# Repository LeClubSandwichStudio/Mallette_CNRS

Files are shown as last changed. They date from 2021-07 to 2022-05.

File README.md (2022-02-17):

# Mallette_CNRS
Water Analyser Briefcase for scientist
> ### Description

> ### [3D View](https://a360.co/3F3qp8W) - models designed by Mathorel Remi (2021)

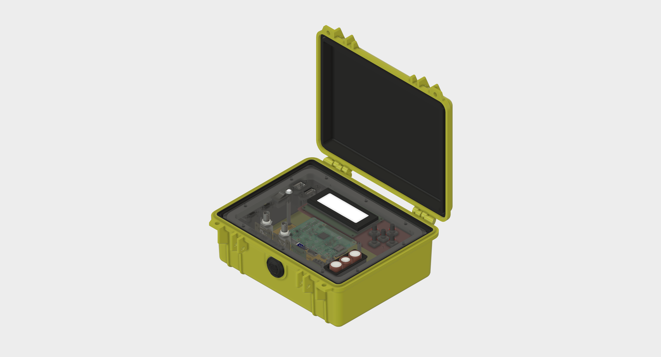
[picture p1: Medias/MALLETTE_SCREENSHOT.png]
mallette screenshot


# Key Features
> ### Hardware

* Protection Case : 
  * Case : [Pelican 1200](https://www.pelican.com/us/en/product/cases/protector/1200) 
  * Panel Frame : [Pelican 1200PF](https://www.pelican.com/us/en/accessory/cases/special-application-panel-frame/1200pf)
* MCU : [Teensy 3.6](https://www.pjrc.com/store/teensy36.html)
* OS : Raspberry Pi 4B - [RaspOS](https://www.raspberrypi.org/software/)
* Sensors : 
  * PH : [SEN0161-V2](https://wiki.dfrobot.com/Gravity__Analog_pH_Sensor_Meter_Kit_V2_SKU_SEN0161-V2)
  * EC : [DFR0300](https://wiki.dfrobot.com/Gravity__Analog_Electrical_Conductivity_Sensor___Meter_V2__K=1__SKU_DFR0300)
  * Temperature
  * Turbidity

> ### Software

# Summary

# Licence

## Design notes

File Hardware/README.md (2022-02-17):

# Bill Of Materials

> MCU
- [Teensy 3.6](https://www.pjrc.com/store/teensy36.html)

> OS
- [Raspberry Pi 4B](https://www.raspberrypi.org/products/raspberry-pi-4-model-b/)

> Sensors
- [DFRobot Analog Turbidity Sensor](https://wiki.dfrobot.com/Turbidity_sensor_SKU__SEN0189)
- [DFRobot Analog EC Meter V2](https://wiki.dfrobot.com/Gravity__Analog_Electrical_Conductivity_Sensor___Meter_V2__K=1__SKU_DFR0300)
- [DFRobot Analog PH Meter V2](https://wiki.dfrobot.com/Gravity__Analog_pH_Sensor_Meter_Kit_V2_SKU_SEN0161-V2)
- [DFRobot Digital Temperature Sensor](https://wiki.dfrobot.com/Waterproof_DS18B20_Digital_Temperature_Sensor__SKU_DFR0198_)

> Shield
- Custom LCSS Teensy Shield

https://a360.co/3LIjGnY

> Others
- Li-Ion Charger
- Li-Iion Battery
- I/O Switch
- Status Led
-

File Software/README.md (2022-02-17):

# Overview 

| Arduino | Raspberry | Local Website | 
|---|:---:|---:|
| Sensors management | OS | Front interface |
| Sensors Journey | Computing | Commands |

Local AP

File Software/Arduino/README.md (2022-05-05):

# BRIEF

Sample Arduino code to use Water Briefcase Analyzer version 1.2

# FEATURES

- measure temperature
- measure electroconductivity
- measure ph
- measure turbidity (with specific formula)
- check serial to read new commands
- send json to serial 

# DEPENDENCIES

- DFROBOT EC : https://github.com/DFRobot/DFRobot_EC
- DFROBOT PH : https://github.com/DFRobot/DFRobot_PH

# HOW TO RUN ARDUINO

- download Arduino software here : https://www.arduino.cc/en/software

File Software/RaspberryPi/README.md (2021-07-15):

# TABLE OF CONTENTS

- OS Installation
- Remote desktop test and installation
- Server and webpage setup
- Main.py setup

# OS Installation

### Installation [RaspOS](https://www.raspberrypi.org/software/)
> id : pi

> mdp : kmvwqazh

### Installation [Clavier AZERTY](https://www.framboise314.fr/clavier-virtuel-matchbox-en-azerty-sur-le-raspberry-pi/)

### Installation de [RaspAP](https://raspap.com/#quick) 

Dans les paramètres en se connectant au point d’accès,  
> modify password to **"kmvwqazh"**

> modify SSID WIFI name to **"Raspberry_OSI_@MAC"** 

> modify IP to **"10.3.141.X"** 

### Installation [XRDP](https://linuxize.com/post/how-to-install-xrdp-on-raspberry-pi/)

# Remote desktop test and installation

**Work In progress**

*Only use if you need to control remotly the Raspi from your personal desktop without working directly on the Raspi*

# Server and webpage setup

### Check for updates
```python
sudo apt-get update
```
### Upgrade if needed 
```python
sudo apt-get upgrade
```
### Reboot Raspi
```python
sudo reboot
```
### Add permission to modify webpage folder

> First write this in terminal :
```python
sudo chmod -R 777 /var/www/
```
> Then continue typing in terminal :
```python
sudo chmod -R 777 /var/www/*
```
> Check your permission and access
```python
ls -l /var/www/html/
```

### Clear webpage contents
> Go to the repository /home/var/www

> Erase all contents in :file_folder: **www**

### Installation Apache
```python
sudo apt install apache2
```
```python
sudo apt install libapache2-mod-php
```
```python
sudo apt remove lighttpd --yes && sudo service apache2 start
```
> Check it
```python
sudo service --status-all
```

### Html folder
> Copy :file_folder: **html** from github repository

> Past :file_folder: **html** into your local Raspi folder /home/var/www

### Test your html page
> Verify that you are connected to the Raspberry Wifi

> Check if there is any issue with the PHP
```python
sudo tail -n 20 /var/log/apache2/error.log
```
> If there is no issue
```python
sudo service apache2 restart
```
> Reboot the Raspi
```python
sudo reboot 
```
:warning: **Even if you can display the webpage, buttons are not yet running** :warning:

# Main.py Setup

> Copy :page_facing_up: **main.py** from github repository

> Past :page_facing_up: **main.py** into your local Raspi folder /home/Desktop

> Check if it is OK

_Please think to connect the teensy and the Raspi by a usb cable !_

_Please think to upload the Arduino code into the teensy !_

```python
cd Desktop
```
```python
sudo python main.py
```

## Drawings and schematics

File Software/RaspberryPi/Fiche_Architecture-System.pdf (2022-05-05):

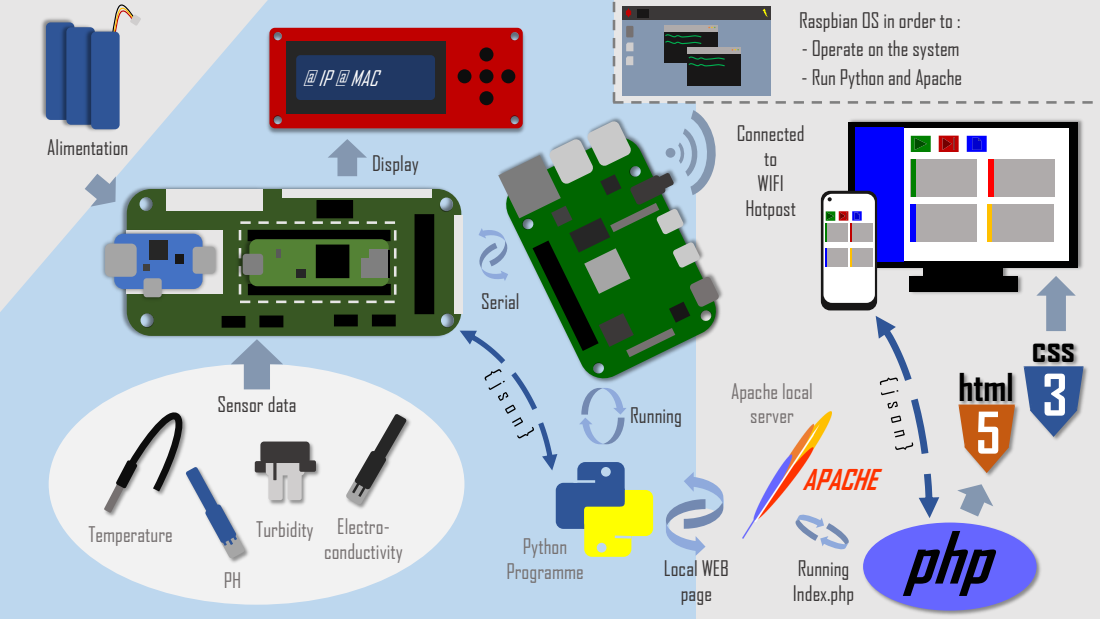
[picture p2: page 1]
php; html 5; css; Sensor data; Alimentation; @ IP @ MAC; Display; Temperature; Turbidity; Electro- conductivity; Serial; Connected to WIFI Hotpost; Running; Python Programme; Apache local server; APACHE; Local WEB page; Running Index.php

Raspbian OS in order to :
- Operate on the system
- Run Python and Apache

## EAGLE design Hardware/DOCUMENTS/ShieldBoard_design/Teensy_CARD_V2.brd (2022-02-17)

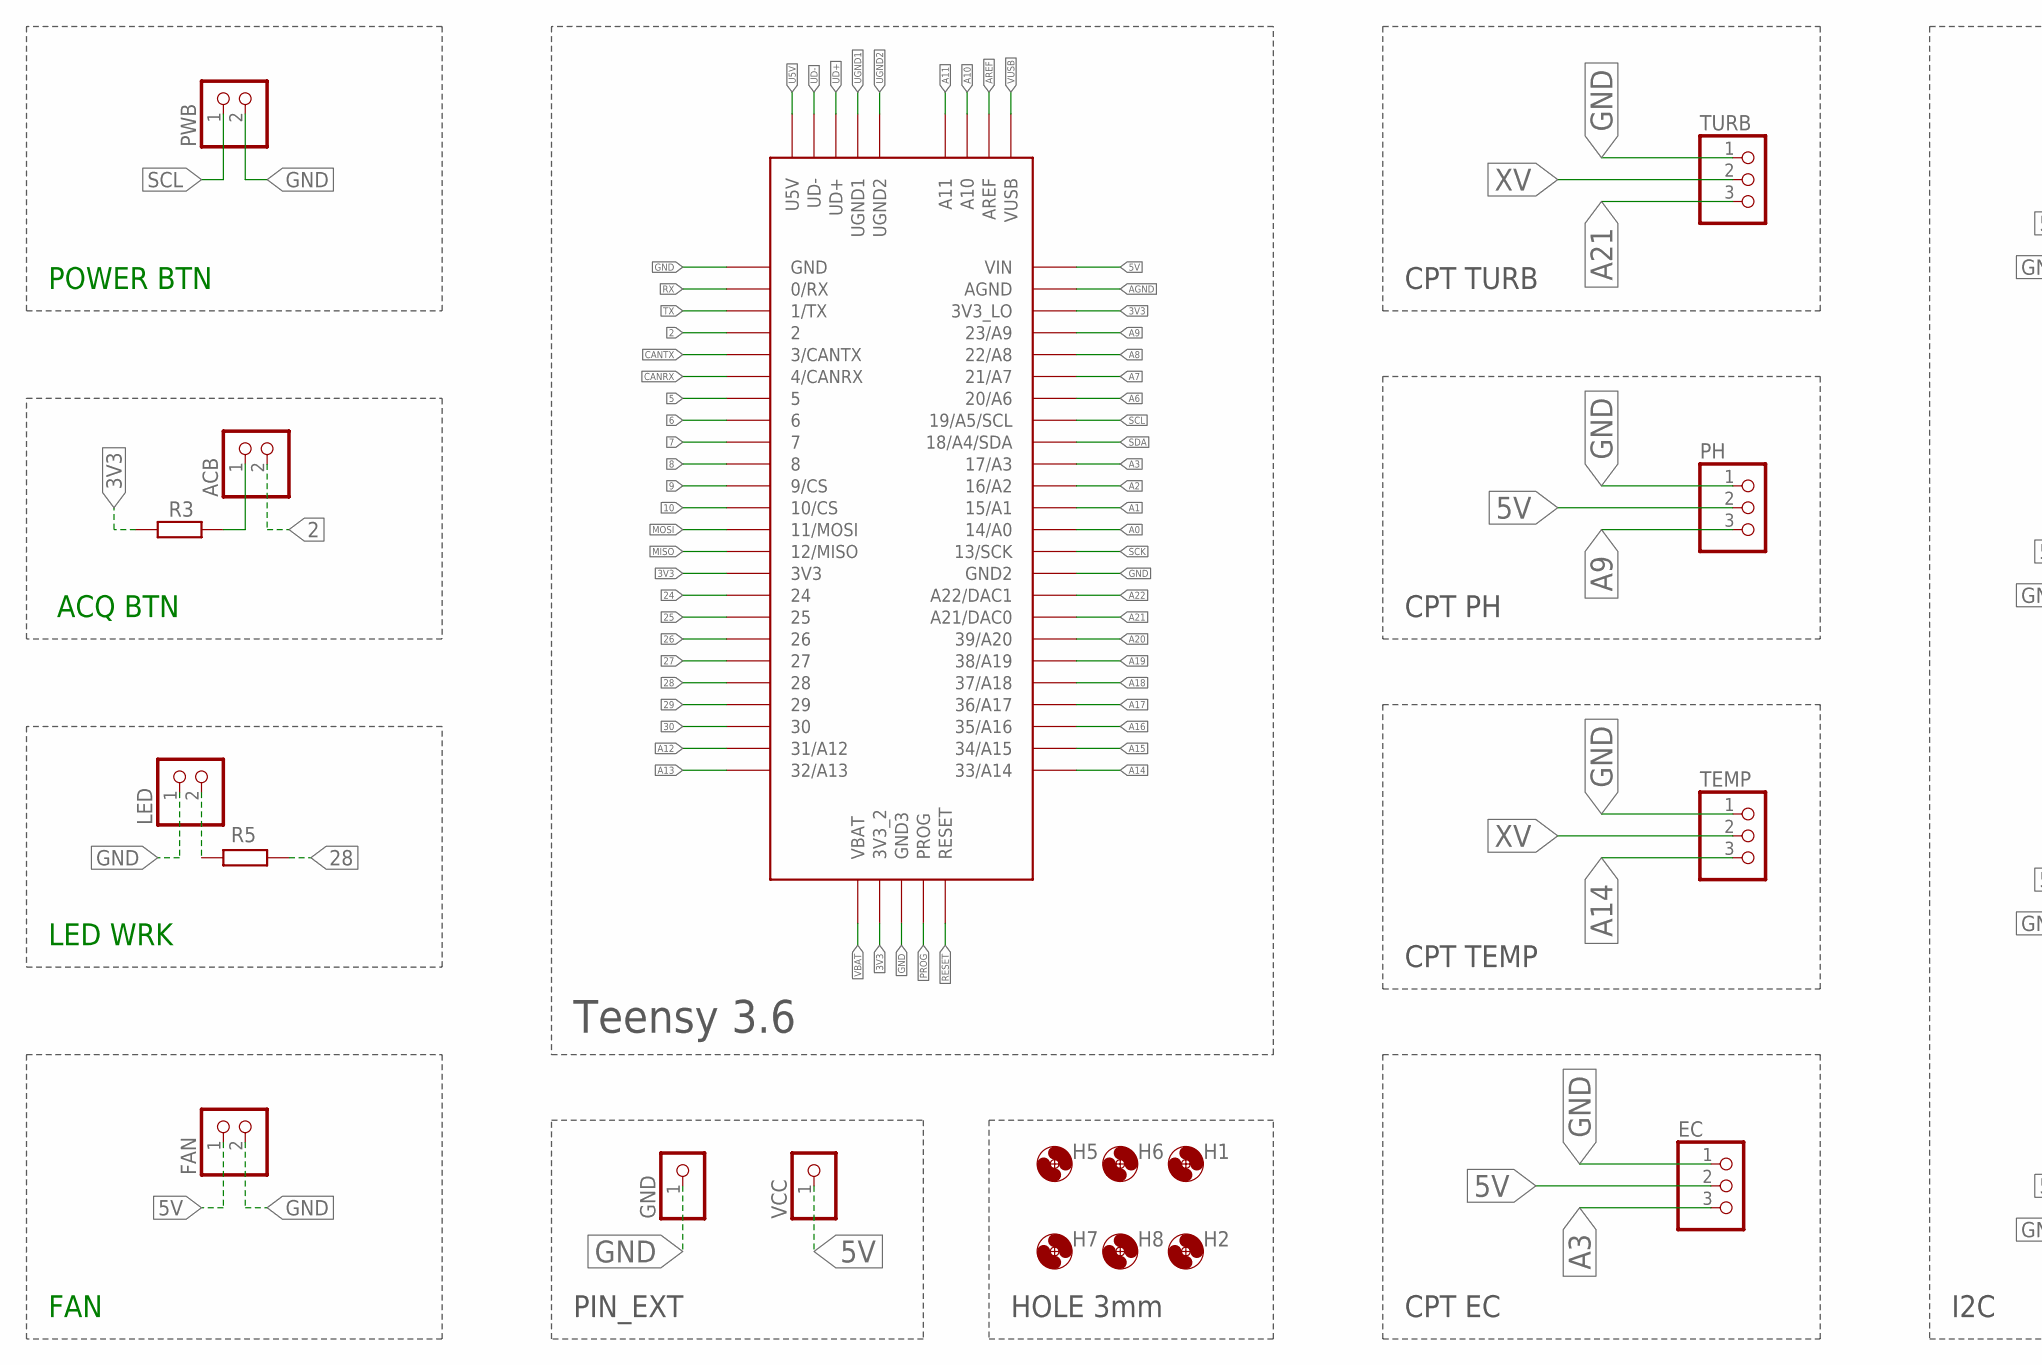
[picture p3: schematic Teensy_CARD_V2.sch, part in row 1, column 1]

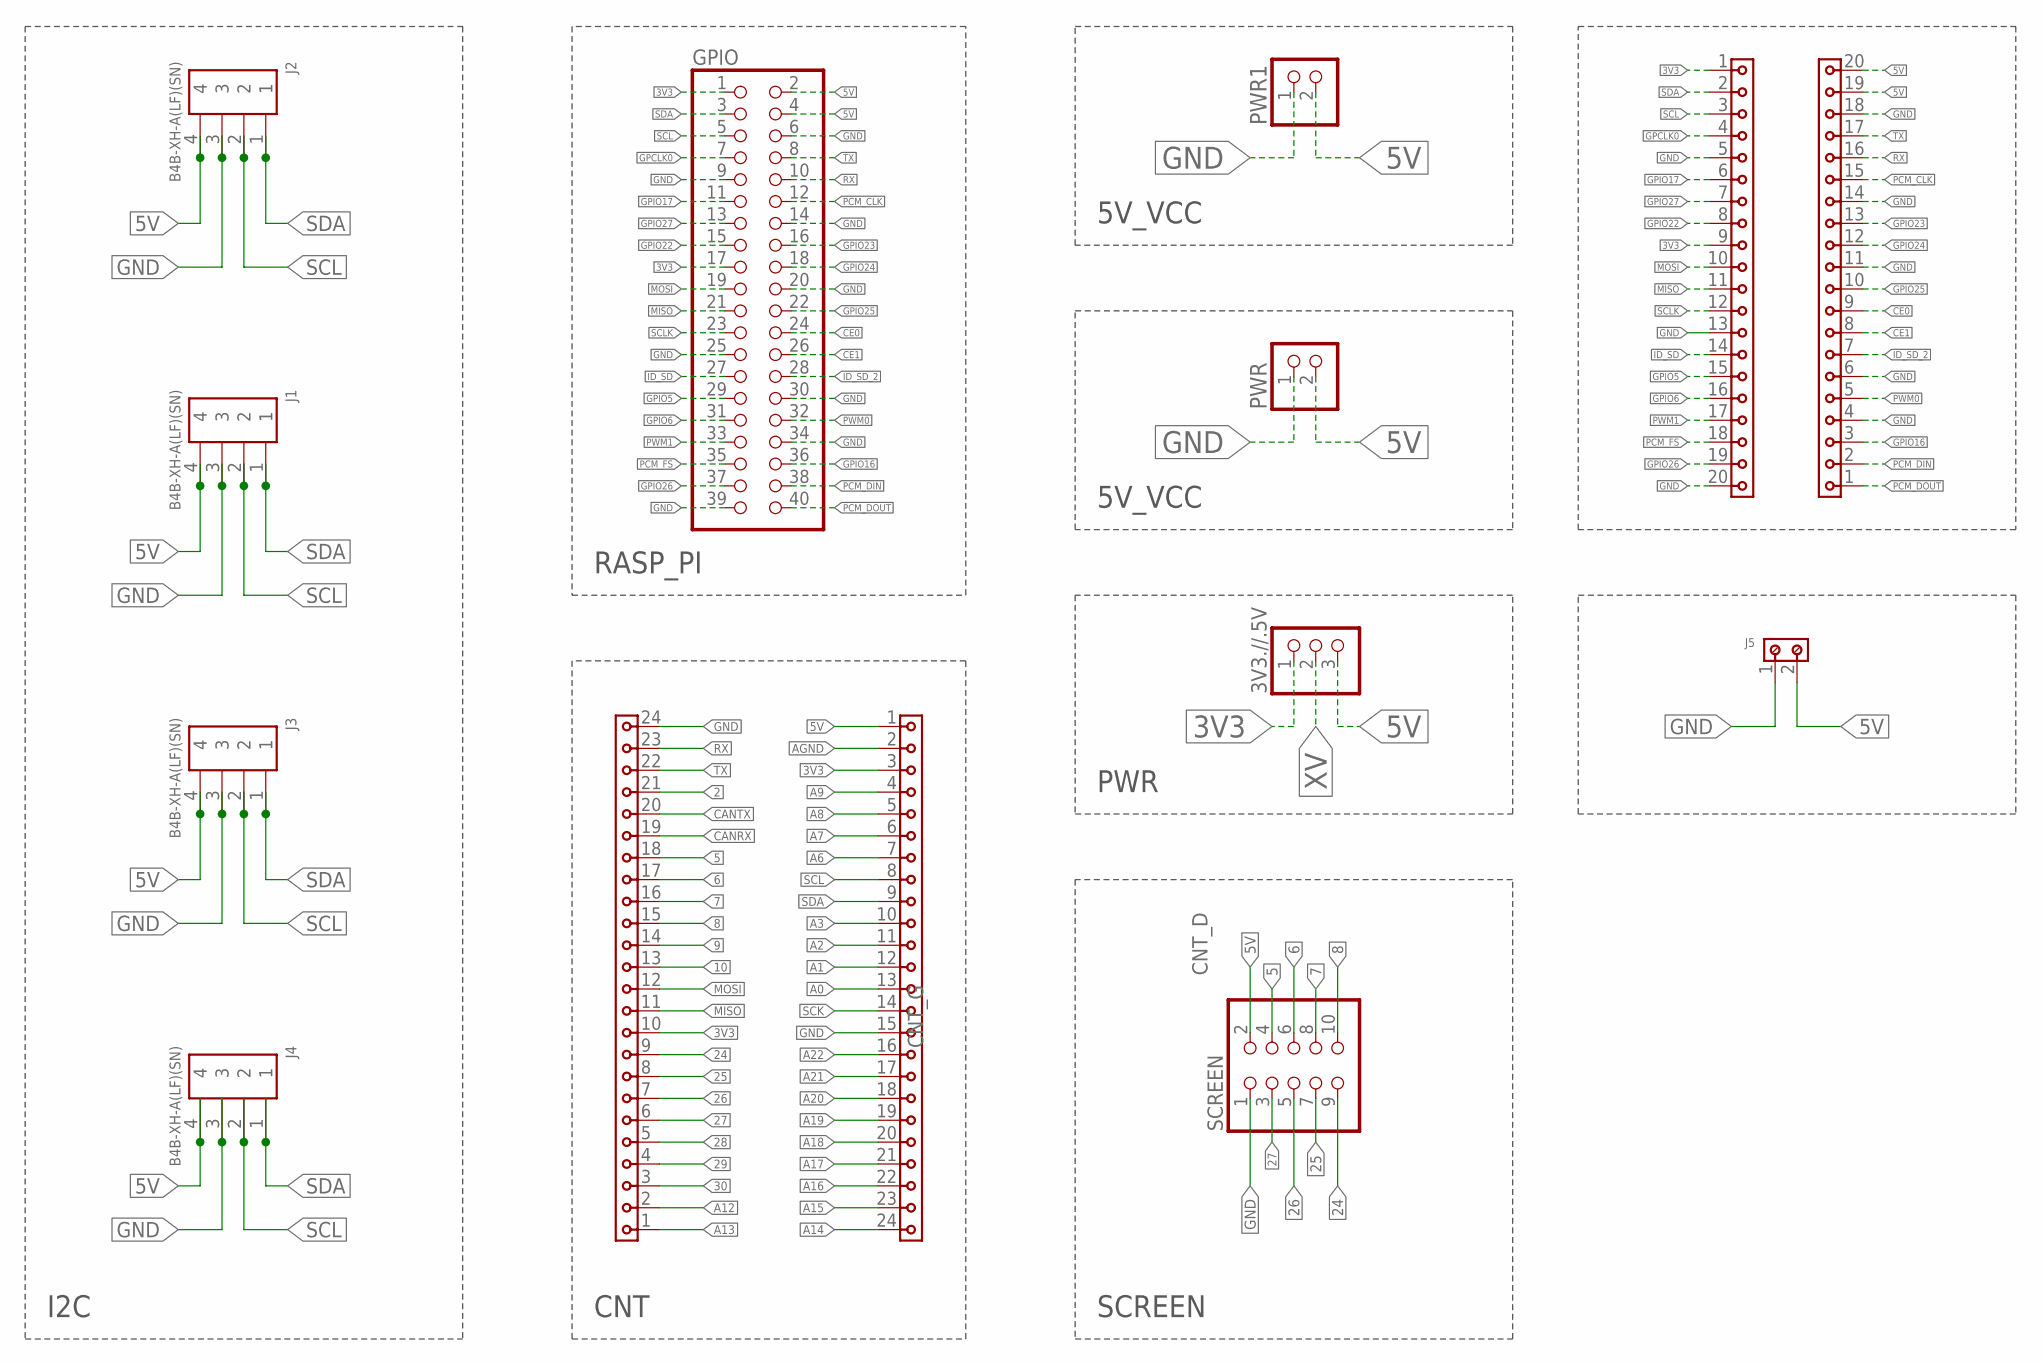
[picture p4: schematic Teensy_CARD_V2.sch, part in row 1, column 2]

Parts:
3V3.//.5V: PINHD-1X3; 1X03
ACB: PINHD-1X2; 1X02
CNT_D: 6130XX11821_61302411821; 61302411821
CNT_G: 6130XX11821_61302411821; 61302411821
EC: PINHD-1X3; 1X03
FAN: PINHD-1X2; 1X02
GND: PINHD-1X1; 1X01
GPIO: PINHD-2X20; 2X20
H1, H2, H5, H6, H7, H8: MOUNT-HOLE3.0; 3,0
J1, J2, J3, J4: B4B-XH-A(LF)(SN)
J5: 691213510002
JP1, JP2: 6130XX11821_61302011821; 61302011821
LED: PINHD-1X2; 1X02
PH: PINHD-1X3; 1X03
PWB: PINHD-1X2; 1X02
PWR, PWR1: PINHD-1X2; 1X02
R3, R5: R-EU_0207/10; 0207/10
SCREEN: PINHD-2X5; 2X05
TEMP: PINHD-1X3; 1X03
TURB: PINHD-1X3; 1X03
U$1: TEENSY_3.5/3.6
VCC: PINHD-1X1; 1X01

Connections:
2: ACB.2, CNT_G.21, U$1.2
3V3: 3V3.//.5V.1, CNT_D.3, CNT_G.10, GPIO.1, GPIO.17, JP1.1, JP1.9, R3.1, U$1.3V3, U$1.3V3_2, U$1.3V3_LO
5: CNT_G.18, SCREEN.4, U$1.5
5V: 3V3.//.5V.3, CNT_D.1, EC.2, FAN.1, GPIO.2, GPIO.4, J1.4, J2.4, J3.4, J4.4, J5.2, JP2.19, JP2.20, PH.2, PWR.2, PWR1.2, SCREEN.2, U$1.VIN, VCC.1
6: CNT_G.17, SCREEN.6, U$1.6
7: CNT_G.16, SCREEN.8, U$1.7
8: CNT_G.15, SCREEN.10, U$1.8
9: CNT_G.14, U$1.9/CS
10: CNT_G.13, U$1.10/CS
24: CNT_G.9, SCREEN.9, U$1.24
25: CNT_G.8, SCREEN.7, U$1.25
26: CNT_G.7, SCREEN.5, U$1.26
27: CNT_G.6, SCREEN.3, U$1.27
28: CNT_G.5, R5.1, U$1.28
29: CNT_G.4, U$1.29
30: CNT_G.3, U$1.30
A0: CNT_D.13, U$1.14/A0
A1: CNT_D.12, U$1.15/A1
A2: CNT_D.11, U$1.16/A2
A3: CNT_D.10, EC.3, U$1.17/A3
A6: CNT_D.7, U$1.20/A6
A7: CNT_D.6, U$1.21/A7
A8: CNT_D.5, U$1.22/A8
A9: CNT_D.4, PH.3, U$1.23/A9
A10: U$1.A10
A11: U$1.A11
A12: CNT_G.2, U$1.31/A12
A13: CNT_G.1, U$1.32/A13
A14: CNT_D.24, TEMP.3, U$1.33/A14
A15: CNT_D.23, U$1.34/A15
A16: CNT_D.22, U$1.35/A16
A17: CNT_D.21, U$1.36/A17
A18: CNT_D.20, U$1.37/A18
A19: CNT_D.19, U$1.38/A19
A20: CNT_D.18, U$1.39/A20
A21: CNT_D.17, TURB.3, U$1.21/DAC0 (A21/DAC0)
A22: CNT_D.16, U$1.A22/DAC1
AGND: CNT_D.2, U$1.AGND
AREF: U$1.AREF
CANRX: CNT_G.19, U$1.4/CANRX
CANTX: CNT_G.20, U$1.3/CANTX
CE0: GPIO.24, JP2.9
CE1: GPIO.26, JP2.8
GND: CNT_D.15, CNT_G.24, EC.1, FAN.2, GND.1, GPIO.6, GPIO.9, GPIO.14, GPIO.20, GPIO.25, GPIO.30, GPIO.34, GPIO.39, J1.3, J2.3, J3.3, J4.3, J5.1, JP1.5, JP1.13, JP1.20, JP2.4, JP2.6, JP2.11, JP2.14, JP2.18, LED.1, PH.1, PWB.2, PWR.1, PWR1.1, SCREEN.1, TEMP.1, TURB.1, U$1.GND, U$1.GND2, U$1.GND3
GPCLK0: GPIO.7, JP1.4
GPIO5: GPIO.29, JP1.15
GPIO6: GPIO.31, JP1.16
GPIO16: GPIO.36, JP2.3
GPIO17: GPIO.11, JP1.6
GPIO22: GPIO.15, JP1.8
GPIO23: GPIO.16, JP2.13
GPIO24: GPIO.18, JP2.12
GPIO25: GPIO.22, JP2.10
GPIO26: GPIO.37, JP1.19
GPIO27: GPIO.13, JP1.7
ID_SD: GPIO.27, JP1.14
ID_SD_2: GPIO.28, JP2.7
MISO: CNT_G.11, GPIO.21, JP1.11, U$1.12/MISO
MOSI: CNT_G.12, GPIO.19, JP1.10, U$1.11/MOSI
unnamed: ACB.1, R3.2
unnamed: LED.2, R5.2
PCM_CLK: GPIO.12, JP2.15
PCM_DIN: GPIO.38, JP2.2
PCM_DOUT: GPIO.40, JP2.1
PCM_FS: GPIO.35, JP1.18
PROG: U$1.PROG
PWM0: GPIO.32, JP2.5
PWM1: GPIO.33, JP1.17
RESET: U$1.RESET
RX: CNT_G.23, GPIO.10, JP2.16, U$1.0/RX
SCK: CNT_D.14, U$1.13/SCK
SCL: CNT_D.8, GPIO.5, J1.2, J2.2, J3.2, J4.2, JP1.3, PWB.1, U$1.19/A5/SCL
SCLK: GPIO.23, JP1.12
SDA: CNT_D.9, GPIO.3, J1.1, J2.1, J3.1, J4.1, JP1.2, U$1.18/A4/SDA
TX: CNT_G.22, GPIO.8, JP2.17, U$1.1/TX
U5V: U$1.U5V
UD+: U$1.UD+
UD-: U$1.UD-
UGND1: U$1.UGND1
UGND2: U$1.UGND2
VBAT: U$1.VBAT
VUSB: U$1.VUSB
XV: 3V3.//.5V.2, TEMP.2, TURB.2

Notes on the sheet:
Teensy 3.6
CPT TEMP
CPT PH
CPT TURB
CPT EC
HOLE 3mm
PWR
CNT
5V_VCC
PIN_EXT
RASP_PI
I2C
SCREEN
FAN
POWER BTN
ACQ BTN
LED WRK

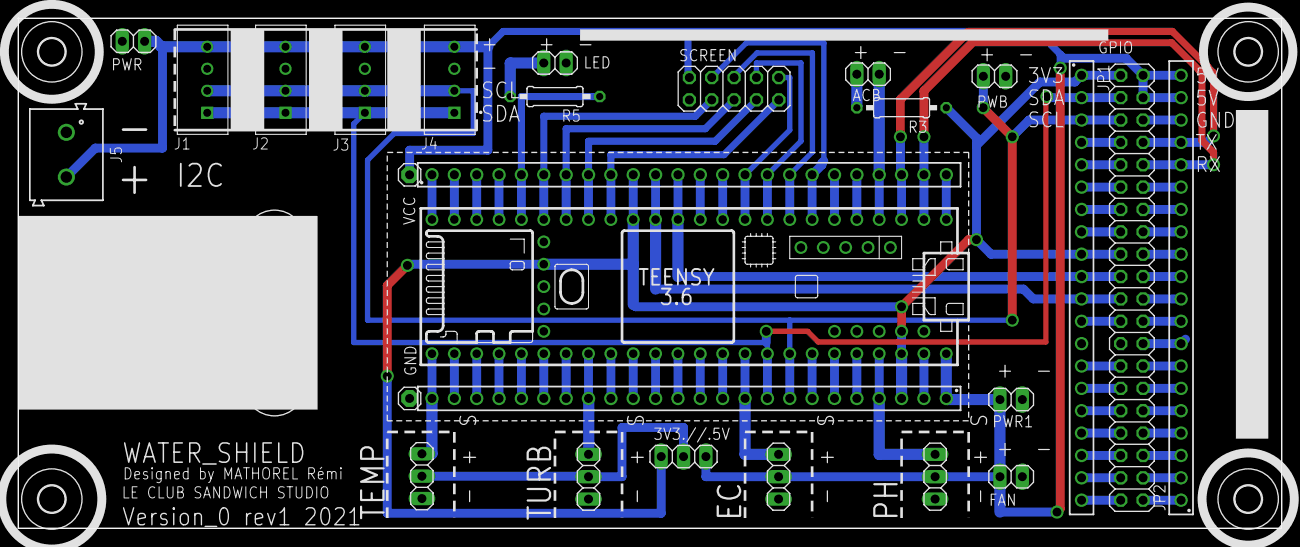
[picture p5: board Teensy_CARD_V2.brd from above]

Board: 2 copper layers, 143.5 x 57.9 mm, 33 parts (0 on the bottom side), 71 nets.

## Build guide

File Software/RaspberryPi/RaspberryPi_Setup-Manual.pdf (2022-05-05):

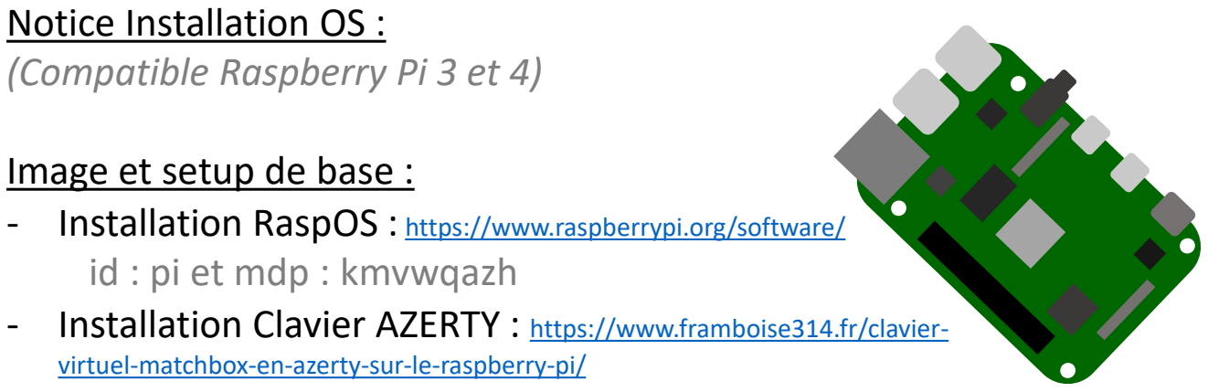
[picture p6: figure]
Notice Installation OS : (Compatible Raspberry Pi 3 et 4); Image et setup de base :; id : pi et mdp : kmvwqazh; virtuel-matchbox-en-azerty-sur-le-raspberry-pi/

- Installation RaspOS : https://www.raspberrypi.org/software/
- Installation Clavier AZERTY : https://www.framboise314.fr/clavier-
- Installation de RaspAP : https://raspap.com/#quick
Dans les paramètres en se connectant au point d’accès, modifier le mdp en : kmvwqazh et le nom de la WIFI en Raspberry_OSI_@MAC et enfin modifier l'IP en 10.3.141.X
- Installation XRDP : https://linuxize.com/post/how-to-install-xrdp-onraspberry-pi/ (https://linuxize.com/post/how-to-install-xrdp-on-raspberry-pi/)

Assistance à distance avec XRDP :
L’XRDP permet le « remote desktop », pour cela il faut :
- se connecter au wifi pré-paramétré

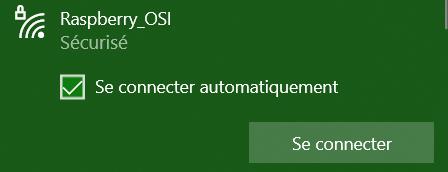
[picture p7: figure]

- Tapez dans la barre de recherche Windows : « remote desktop » et cliquez sur l’application suivante :
- Ensuite y rentrez l’IP paramétré avec RaspAP :

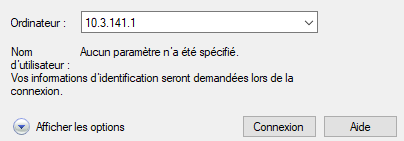
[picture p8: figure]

- Cliquez sur Connexion puis entrer :

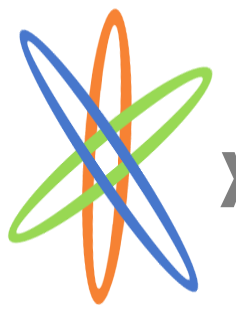
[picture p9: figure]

- Validez et voilà, vous avez accès à votre bureau !

# xr d p

Setup serveur et site :
Une fois l’image installer, se rendre sur la console et taper les commandes suivantes (en acceptant avec y si demandé) :
- sudo apt-get update
- sudo apt-get upgrade
- sudo reboot
- sudo chmod -R 777 /var/www/*
cette commande permet d’avoir les accès pour modifier les fichiers du site. (commande vérification des droits : ls -l /var/www/html/)
- Se rendre dans fichier en haut à gauche puis dans le répertoire /var/www et supprimer tout les fichiers qui présents.
- sudo apt install apache2
- sudo apt install libapache2-mod-php
permet l’intallation du module php pour apache2.
- sudo apt remove lighthttpd --yes && sudo service apache2 start suppression de lighthttpd qui empêche apache2 de démarrer et lance le serveur d’apache2. (commande de vérification du lancement d’apache 2 : sudo service --status-all)
- Copier le fichier html du drive dans /var/www/
- Le site doit être accessible en tapant l'IP dans la barre de recherche (vérifier : d'être connecté sur le hotspot)
Si le site fonctionne mais qu’il semble « buggé » se rendre dans les commandes Raspbian OS et taper la commande suivante pou vérifier si l’erreur proviens du PHP : sudo tail -n 20 /var/log/apache2/error.log si aucunes erreurs apparait tapez la commande suivant : sudo service apache2 restart puis redémarrez la Raspberry avec la commande : sudo reboot
(il est normal que les bouton ne fonctionnent pas encore)

### APACHE

# php

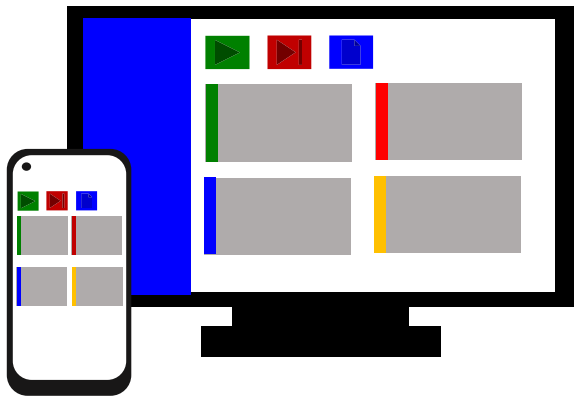
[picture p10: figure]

## html

5

## css

3

Configuration de la Teensy 3.6 :
- Installer l’IDE Arduino version 1.8.13 :
https://www.arduino.cc/en/main/OldSoftwareReleases
- Installer le module Teensy : https://www.pjrc.com/teensy/td_download.html
- Décompresser et ouvrir le programme du drive
- Brancher la Teensy (vérifier port) puis lancer l’upload du programme
- Ensuite brancher la Teensy sur la Raspberry

Configuration du python (main.py) :
- Copier le main.py du drive sur le bureau de la Raspberry
- Vérifier que le code fonctionne en tapant les commandes suivantes
- cd Desktop
- sudo python main.py
Vérifier ensuite le code en lançant le site et en appuyant sur start (la Teensy doit être relié à la Raspberry)
- Appliquer la procédure suivante pour lancer le main.py au

démarrage : https://www.raspberrypi-france.fr/lancer-un-script-python-au-demarrage-duraspberry-pi/ (https://www.raspberrypi-france.fr/lancer-un-script-python-au-demarrage-du-raspberry-pi/)

Utilisation du site :
- Dashbord :
Il se compose pour l’instant d’un bouton start pour démarrer l’acquisition des données, pour ce faire il faut s’assurer que la Teensy 3.6 est bien connecté et que le main.py tourne bien en arrière plan.

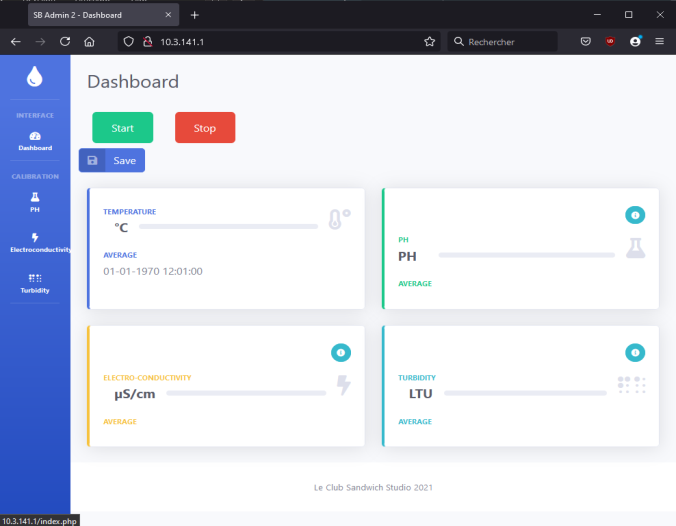
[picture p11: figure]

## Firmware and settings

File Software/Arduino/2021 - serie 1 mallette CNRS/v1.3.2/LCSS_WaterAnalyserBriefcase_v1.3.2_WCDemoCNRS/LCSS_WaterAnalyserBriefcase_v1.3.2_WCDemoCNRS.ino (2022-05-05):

/*
 * file LCSS_WaterAnalyserBriefcase_v1.3.2
 * THIS CODE IS USED FOR CNRS WATER BRIEFCASE UNIT
 * Modified 18 march 2022 by Antoine BERR
 * 
 * v1.3.2 : 
 * BIG UPDATES
 * > add LBO control to check battery status
 * > add battery check during setup & loop
 * GLOBAL CHANGES
 * > clean some lines
 * > add some serial comments on setup 
 */

//////////////////////////////////////////////////
//                  Bill of Materials
/////////////////////////////////////////////////


//////////////////////////////////////////////////
//                  Wiring
/////////////////////////////////////////////////
/*

GND ->GND 
VCC:
  EC and PH:                  VCC to VIN (closest pin to usb connector in the corner)
  Temperature and turbidity:  VCC to 3.3v (third pin from the usb connector, same side as VIN)
Signal wire:
  EC          -> 17 (A3)
  Tunbidity   -> A21
  Temperature -> 33 (A14)
  PH          -> 23 (A9)
  
*/
//////////////////////////////////////////////////
//                  Commands
/////////////////////////////////////////////////
/*
  {"command":"start"}
  {"command":"stop"}
  {"command":"restart"}
  {"setinterval":"999"}

 *  PH Calibration：
 *   enterph -> enter the PH calibration mode
 *   calph   -> calibrate with the standard buffer solution, two buffer solutions(4.0 and 7.0) will be automaticlly recognized
 *   exitph  -> save the calibrated parameters and exit from PH calibration mode
 *
 *  EC Calibration：
 *   enterec -> enter the EC calibration mode
 *   calec   -> calibrate with the standard buffer solution, two buffer solutions(1413us/cm and 12.88ms/cm) will be automaticlly recognized
 *   exitec  -> save the calibrated parameters and exit from EC calibration mode
  
*/

//////////////////////////////////////////////////
//              PIN configuration
/////////////////////////////////////////////////
#define PHPIN  23
#define TEMPPIN 33
#define ECPIN  17
#define TURBPINSENSOR A21

#define LBO 28
#define LBO_PULLUP 30
int lbo_state;


//////////////////////////////////////////////////
//                  Libraries
/////////////////////////////////////////////////
#include <ArduinoJson.h>
#include "Korzhenevskiy_tick_tack_2.h"
#include "DFRobot_PH.h"
#include "DFRobot_EC.h"
#include <EEPROM.h>
#include <OneWire.h>
#include <TimeLib.h>
#include <stdio.h>
#include <time.h>
#include <LiquidCrystal.h>
#include <Math.h>

#include <TimeLib.h>

//////////////////////////////////////////////////
//                Declarations
/////////////////////////////////////////////////
void measure_sensors();
OneWire ds(TEMPPIN);
float phValue, temperature, turbidity, turbidityNTU, ecValue, voltageTurb, voltageEC, voltagePH;
DFRobot_PH ph;
DFRobot_EC ec;
Korzhenevskiy_tick_tack_2 sensor_timer(measure_sensors, 1000);
DynamicJsonDocument doc(256);

const int rs = 26, en = 25, d0 = 5, d1 = 6, d2 = 7, d3 = 8;
LiquidCrystal lcd(rs, en, d0, d1, d2, d3);
int i=0;
int p=0;

byte customChars[8][8] = {
    {B00000,B00000,B00000,B00000,B00000,B00001,B00011,B00101},
    {B00000,B00000,B00000,B00010,B10000,B01101,B11000,B11110},
    {B00000,B00000,B00010,B01000,B01100,B10010,B01100,B00010},
    {B01110,B01110,B01111,B11110,B11110,B11111,B11111,B11111},
    {B11100,B11100,B01100,B11110,B10111,B11001,B00111,B11101},
    {B10000,B00000,B00000,B00000,B00000,B10000,B11100,B11111},
    {B11111,B11111,B00000,B00000,B11111,B00000,B11111,B11111},
    {B11111,B11111,B00000,B11111,B00000,B00000,B00000,B00000}
};

byte Data[2][8] = {
    {B00000,B11111,B01010,B00111,B00010,B00010,B00010,B00010},
    {B00000,B11000,B10000,B00001,B00001,B00101,B10101,B10101}
};

int val=0;
void drawBanner();



//////////////////////////////////////////////////
//                   setup
/////////////////////////////////////////////////
void setup() {
  //sensor_timer.start();

  setSyncProvider(getTeensy3Time);
  
  Serial.begin(9600);
  Serial.println("START SERIAL");
  Serial.println("START RTC CHECK");
  delay(1000);
  if (timeStatus()!= timeSet) {
    Serial.println("Unable to sync with the RTC");
  } else {
    Serial.println("RTC has set the system time");
    displayTeensyTime();
  }

  Serial.println("PH SENSOR BEGIN");
  ph.begin();
  Serial.println("EC SENSOR BEGIN");
  ec.begin();
  Serial.println("SET PIN MODE");
  pinMode(2, OUTPUT);
  pinMode(3, OUTPUT);
  pinMode(4, OUTPUT);
  pinMode(5, OUTPUT);
  pinMode(9, OUTPUT);
  pinMode(10, OUTPUT);
  pinMode(24, INPUT);
  // init LBO pins
  pinMode(30, INPUT_PULLUP);
  pinMode(28, OUTPUT);

  Serial.println("LCD BEGIN");
  lcd.begin(20, 4);
  for(int i = 0; i < 8; i++)
    lcd.createChar(i, customChars[i]);    
    for(int i = 17;  i >= 0; i--){
        lcd.clear();
        drawBanner(i);
        delay(250);
    }
  delay(2500);
  
  if (p==0){
    
    lcd_print_LCSS_banner();

    delay(250);
    lcd.clear();
    lcd.setCursor(3, 2);
    lcd.print("LOADING . . . ");
    delay(250);
    p=2;
    delay(3000);
    
  }

    lcd.clear();
    lcd.home();
    lcd.setCursor(0, 0);
    lcd.print("WIFI: WaterCase_Demo");
    lcd.setCursor(1, 1);
    lcd.print("MDP: kmvwqazh");
    lcd.createChar(0, Data[0]);
    lcd.setCursor(1, 3);
    lcd.write(byte(0));
    lcd.createChar(1, Data[1]);
    lcd.setCursor(2, 3);
    lcd.write(byte(1));  
    lcd.setCursor(4, 3);
    lcd.print("IP: 10.3.141.1");
    p=2;

    Serial.println("CHECK BATTERY STATUS");
    delay(2000);
    SETUP_check_battery();
    Serial.println("CHECK BATTERY : done !");
}

void drawBanner(int offset){
    for(int j = 1; j < 3; j++){
        for(int i = 0; i < 3; i++){
            lcd.setCursor(offset+i, j);
            int characterIndex = (j-1) * 3 + i;
            lcd.write(byte(characterIndex));
        }
    }
    
    lcd.setCursor(offset+4,1);
    lcd.write("WATER ANALYSER");
    lcd.setCursor(offset+7,2);
    lcd.write("BRIEFCASE");    
    
}

void SETUP_check_battery(){
  lbo_state = digitalRead(LBO_PULLUP);
    if (lbo_state == HIGH) {
      digitalWrite(LBO, LOW);
      Serial.println("this is a HIGH value --- Battery is OK");
    } else {
      digitalWrite(LBO, HIGH);
      Serial.println("this is a LOW value --- Battery is LOW sorry... Please power briefcase !");
    }
  }

 void LOOP_check_battery(){
  lbo_state = digitalRead(LBO_PULLUP);
    if (lbo_state == HIGH) {
      digitalWrite(LBO, LOW);
      //Serial.println("this is a HIGH value --- Battery is OK");
    } else {
      digitalWrite(LBO, HIGH);
      //Serial.println("this is a LOW value --- Battery is LOW sorry... Please power briefcase !");
    }
  }

//////////////////////////////////////////////////
//                  loop
/////////////////////////////////////////////////
void loop() {
    Korzhenevskiy_tick_tack_2::mass_tick();   // check all timers and start if needed
    check_serial();                           // check if new command is received
    
}


//---------------------------------------------------------
//                        SERIAL FEATURES
//---------------------------------------------------------

void check_serial() {
  LOOP_check_battery();
  if (Serial.available() > 0) {
    LOOP_check_battery();
    String data = Serial.readStringUntil('\n');
    Serial.print( "NEW MESSAGE : ");
    Serial.println(data);
    DeserializationError error = deserializeJson(doc, data);
    if (error) {
      Serial.println("JSON parse failed");
    }
    else { // {"command":"start"}
      if ( doc["command"] == "start") {
        Serial.println( "starting sensors");
        sensor_timer.start();
      }
      else if ( doc["command"] == "stop") {
        Serial.println( "stopping sensors");
        sensor_timer.stop ();
      }//{"setinterval":"999"}
      else if ( doc.containsKey("setinterval")) {
        int newinterval = doc["setinterval"];
        if ((newinterval > 500) && (newinterval < 1000 * 60)) {
          Serial.print( "setting new sensor interval");
          Serial.println(newinterval);
          sensor_timer.setinterval (newinterval);
        }
        else Serial.println("this interval is not allowed (500ms-1m)");
      }
      else if (doc["command"] == "restart") {

        delay(2000);
        _reboot_Teensyduino_();

      }
    }

  }
}


//---------------------------------------------------------
//                        SENSORS FEATURES
//---------------------------------------------------------

void measure_sensors()
{
  analogReadResolution(16);
//---------------------------------------------------------
//                  Temperature
//---------------------------------------------------------
  // READ TEMPERATURE
  temperature = readTemperature(); 
  // ARRONDI AVEC 1 DECIMAL       
  temperature = (round(temperature * 10));
  temperature = temperature / 10;
//---------------------------------------------------------
//                          PH
//---------------------------------------------------------
 // READ PH VOLTAGE
  voltagePH = analogRead(PHPIN) / 65535.0 * 3300; // read the voltage
  // ARRONDI AVEC 1 DECIMAL 
  voltagePH = (round(voltagePH * 10));
  voltagePH = voltagePH / 10;

  // CALCULATE PH VALUE
  phValue = ph.readPH(voltagePH, temperature); // convert voltage to pH with temperature compensation
  // ARRONDI AVEC 1 DECIMAL 
  phValue = (round(phValue * 10));
  phValue = phValue / 10;
//---------------------------------------------------------
//                     Turbidity
//---------------------------------------------------------
  // READ TURB VOLT
  voltageTurb = (analogRead(TURBPINSENSOR) / 65535.0 * 3300);
  // ARRONDI AVEC 1 DECIMAL 
  voltageTurb = (round(voltageTurb * 10));
  voltageTurb = voltageTurb / 10;

  // CALCULATE TURB VALUE
  // Please that voltage needs to be in Volts to integrate the formula
  turbidity = ((voltageTurb/1000 - 2.128)/-0.7021)*1000;

//---------------------------------------------------------
//                     Turbidity OFFSET here
//---------------------------------------------------------
  // Precize value with offset calculated with scientist per briefcase
  
  turbidity =  0.893 * turbidity - 52.658;
  
  // ARRONDI AVEC 1 DECIMAL
  turbidity = (round(turbidity * 10));
  turbidity = turbidity / 10;
//---------------------------------------------------------
//                        EC
//---------------------------------------------------------
  // READ EC VOLT
  voltageEC = analogRead(ECPIN) / 65535.0 * 3300;
  // ARRONDI AVEC 1 DECIMAL
  voltageEC = (round(voltageEC * 10));
  voltageEC = voltageEC / 10;

  // CALCULATE EC VALUE
  ecValue    = ec.readEC(voltageEC, temperature);      // convert voltage to EC with temperature compensation
  ecValue = ecValue * 1000;
  //  ARRONDI AVEC 0 decimal
  ecValue = (round(ecValue * 1));

//---------------------------------------------------------
//                        JSON
//---------------------------------------------------------

  send_json();

}


void  send_json() {
  //float phValue, temperature, turbidity, turbidityNTU, ec;
  DynamicJsonDocument doc(256);
  doc["from"] = "Teensy";
  JsonObject sensors = doc.createNestedObject("sensors");
  sensors["temperature"] = temperature;
  sensors["ph"] = phValue;
  sensors["ph_voltage"] = voltagePH;
  sensors["ec"] = ecValue;
  sensors["ec_voltage"] = voltageEC;
  sensors["turbidity"] = turbidity;
  sensors["turb_voltage"] = voltageTurb;
  unsigned long Time = Teensy3Clock.get();
  sensors["time"]= Time;

  serializeJson(doc, Serial);
  Serial.println();



}

//---------------------------------------------------------
//                        TIME FEATURES
//---------------------------------------------------------

void displayTeensyTime() {
  if (Serial.available()) {
    time_t t = processSyncMessage();
    if (t != 0) {
      Teensy3Clock.set(t); // set the RTC
      setTime(t);
    }
  }
  digitalClockDisplay();  
  delay(1000);
}
void digitalClockDisplay() {
  // digital clock display of the time
  Serial.print(hour());
  printDigits(minute());
  printDigits(second());
  Serial.print(" ");
  Serial.print(day());
  Serial.print(" ");
  Serial.print(month());
  Serial.print(" ");
  Serial.print(year()); 
  Serial.println(); 
}

time_t getTeensy3Time()
{
  return Teensy3Clock.get();
}

/*  code to process time sync messages from the serial port   */
#define TIME_HEADER  "T"   // Header tag for serial time sync message

unsigned long processSyncMessage() {
  unsigned long pctime = 0L;
  const unsigned long DEFAULT_TIME = 1357041600; // Jan 1 2013 

  if(Serial.find(TIME_HEADER)) {
     pctime = Serial.parseInt();
     return pctime;
     if( pctime < DEFAULT_TIME) { // check the value is a valid time (greater than Jan 1 2013)
       pctime = 0L; // return 0 to indicate that the time is not valid
     }
  }
  return pctime;
}

void printDigits(int digits){
  // utility function for digital clock display: prints preceding colon and leading 0
  Serial.print(":");
  if(digits < 10)
    Serial.print('0');
  Serial.print(digits);
}

float readTemperature()
{
  //add your code here to get the temperature from your temperature sensor
  //returns the temperature from one DS18S20 in DEG Celsius

  byte data[12];
  byte addr[8];

  if ( !ds.search(addr)) {
    //no more sensors on chain, reset search
    ds.reset_search();
    return -1000;
  }

  if ( OneWire::crc8( addr, 7) != addr[7]) {
    Serial.println("CRC is not valid!");
    return -1000;
  }

  if ( addr[0] != 0x10 && addr[0] != 0x28) {
    Serial.print("Device is not recognized");
    return -1000;
  }

  ds.reset();
  ds.select(addr);
  ds.write(0x44, 1); // start conversion, with parasite power on at the end

  byte present = ds.reset();
  ds.select(addr);
  ds.write(0xBE); // Read Scratchpad


  for (int i = 0; i < 9; i++) { // we need 9 bytes
    data[i] = ds.read();
  }

  ds.reset_search();

  byte MSB = data[1];
  byte LSB = data[0];

  float tempRead = ((MSB << 8) | LSB); //using two's compliment
  float TemperatureSum = tempRead / 16;

  return TemperatureSum;
}

//---------------------------------------------------------
//                        LCD SCREENS
//---------------------------------------------------------

void lcd_print_LCSS_banner(){
  lcd.clear();
  lcd.home();
  lcd.blink();
  lcd.setCursor(2, 0);
  lcd.print("L");delay(250);lcd.print("E");delay(150);lcd.print(" ");delay(250);lcd.print("C");delay(250);lcd.print("L");delay(250);lcd.print("U");delay(250);lcd.print("B");delay(250);
  lcd.setCursor(10, 1);
  lcd.print("S");delay(250);lcd.print("A");delay(250);lcd.print("N");delay(250);lcd.print("D");delay(250);lcd.print("W");delay(250);lcd.print("I");delay(250);lcd.print("C");delay(250);lcd.print("H");
  lcd.setCursor(3, 2);
  lcd.print("S");delay(250);lcd.print("T");delay(250);lcd.print("U");delay(250);lcd.print("D");delay(250);lcd.print("I");delay(250);lcd.print("O");delay(250);
  delay(3000);
  lcd.noBlink();
  }

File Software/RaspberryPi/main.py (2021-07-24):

# Check if user as pressed a button on ther website via a file
# Then send a command to the arduino according to user input
# Then wait for data from the arduino to write in a file
# Also writes everything that comes to the serial comm in a log file
import serial
import datetime
import os


# Clear a file
def clearFile(path):
    file = open(path, "w")
    file.close()

# Send a start command to Arduino
def start(int):
    ser.write("{\"command\":\"start\"}\r\n")
    ser.write("{\"setinterval\":\""+int+"\"}\r\n")
    print("start\ninterval =" + int)

# Send a stop command to Arduino
def stop():
    ser.write("{\"command\":\"stop\"}\r\n")
    print("stop")

ser = serial.Serial("/dev/ttyACM0", 9600);

htmlPath = "/var/www/html/logs/"
log_FileName = "Logs.txt"
log_Path = htmlPath + log_FileName
i = 1

while os.path.isfile(log_Path):
    log_FileName = "Logs-{}.txt".format(i)
    log_Path = htmlPath + log_FileName
    i+=1

lastlog = open(htmlPath + "lastlog.txt", "w")
lastlog.write(log_FileName)
lastlog.close()

Logs = open(log_Path, "a")

lastId = 0
_start = False
clearFile("/var/www/html/data/commandeWeb.txt")

while True:
    #Check for user command
    f = open("/var/www/html/data/commandeWeb.txt", "r")
    strList = f.read().split(",")
    print strList[0]

    if strList[0] == '':
        continue

    id = strList[0]

    if id != lastId:
        lastId = id
        command = strList[1]
        if command == "start":
            interval = strList[2]
            start(interval)
            _start = True
        elif command == "stop":
            stop()
            _start = False

    # If user has not input a command or a stop command, do nothing
    if not _start :
        continue

    print("Reading Serial")

    # Else, read serial comm
    line = ser.read_until('\n')

    # If a message is available
    if len(line) == 0:
        print("Serial unavailable")
        continue

    print("Serial received")
    Logs.write(line.decode("utf-8") + " ...\r\n") # Writes to log file
    dataLog = open("/var/www/html/data/data.txt", "w") # Open data log and erase it if it exists

    # Write only json in data log
    if line[0] == "{" :
        dataLog.write(line.decode("utf-8") + " ...\r\n")

    dataLog.close()

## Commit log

2021-07-15 General_Review___code
    - erase old folder
    - update Arduino code
2021-07-22 Add desktop arduino folder
2021-07-24 Add RTC Time feature
    Basic use with Teensy example
2021-07-24 Update Logs files and others
    - Change logs name iteration (date > number) to avoid any issue with non synchronisation date and time
    - Change save button alignment
    - Delete useless demo files from template
    [main.py]
2021-07-29 Add voltage values in JSON
    - Add voltages values for PH, EC, turbidity
    - Update decimal values for each
2022-02-17 Update LCD.ino
    ADD link to ADC buttons control forum
2022-02-17 add teensy shield board files
    add SCH + BRD shield V2 reviewed by Simon JUIF 09/2021
    [Teensy_CARD_V2.brd, Teensy_CARD_V2.sch]
2022-02-17 shield board updates
    updates eagle files teensy board
    [Teensy_CARD_V2.brd, Teensy_CARD_V2.sch]
2022-05-05 Updates Hardware and Arduino features
    * v1.3.2 :
    * BIG UPDATES
    * > add LBO control to check battery status
    * > add battery check during setup & loop
    * GLOBAL CHANGES
    * > clean some lines
    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
2022-05-05 Add EC and PH calibration serial commands

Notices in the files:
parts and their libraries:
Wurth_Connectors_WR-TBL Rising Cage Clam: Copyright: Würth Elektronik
